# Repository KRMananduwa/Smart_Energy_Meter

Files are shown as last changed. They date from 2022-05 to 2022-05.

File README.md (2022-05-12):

# Smart_Energy_Meter
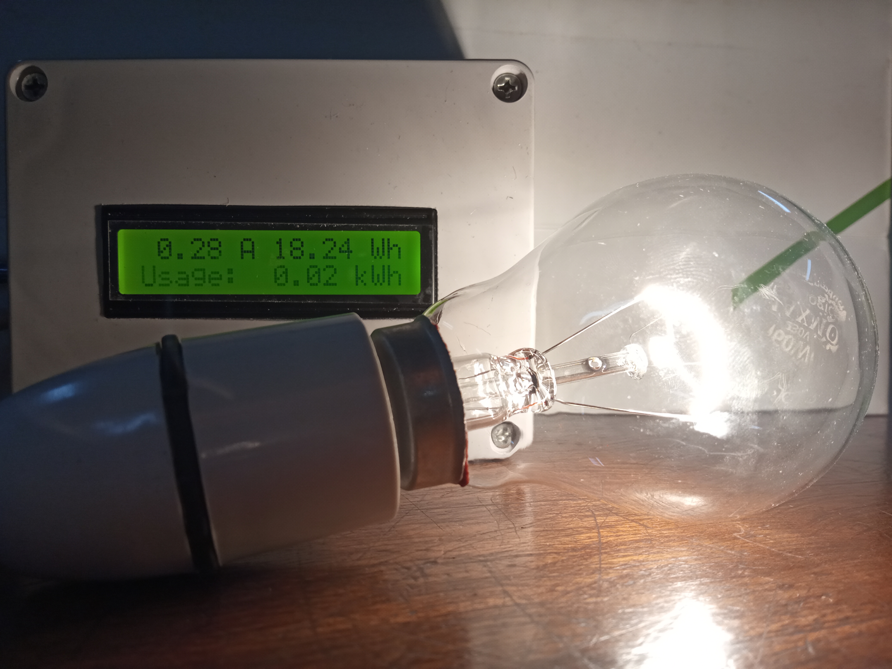
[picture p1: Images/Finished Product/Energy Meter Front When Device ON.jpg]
SmartEnergyMeterImage


A smart energy meter is an electronic device that wirelessly trasnmits information such as consumption of electric energy, voltage levels and current. 
This smart meter can be installed near the meter that supplies power from the mains grid or after the distribution board, indoors or outside the home/office. The speciality of this energy meter can be installed without making any structural changes to your existing electrical supply. The data would be stored in a local database on the computer and can be analysed further.
This project was carried out as a completion of the final year project of the University of Colombo.

https://krmananduwa.github.io/Smart_Energy_Meter/

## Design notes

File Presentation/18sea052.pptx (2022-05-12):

## Smart Energy Meter

Kanishka Rangana (18sea052)

## Abstract

- A smart energy meter is an electronic device that records information such as consumption of electric energy, voltage levels and current.
- This meter is used to know how much energy is consumed.
- The Smart meters communicate the information to the consumer for greater clarity of consumption behavior.

## Overview

- Everyone uses energy but hardly anyone measures it.
- Quantifying is the first step in energy saving.
- Intelligent approach to save energy, cost and selection of equipment.

## Project Aims & Objectives

• Designing compact, rugged and cost-effective smart meter.
• Improving the accuracy of the smart meter.

## Advantages of an Smart Energy Meter

- Determining energy consumption of various equipment
- Determining energy consumption patterns
- Possibility to make informed SMART decisions to reduce energy usage opting for more efficient equipment based on capital cost, ROI.
- Possibility to reduce energy usage by comparing with the initial usage of ones own self
- Possibility to take advantage of off-peak tariff, SMARTLY.

## Methodology

• Material Selection & Cost survey
• Time Planning
• Circuit simulation and prototyping
• Testing & evaluation
• Software and hardware implementation
• Debug errors and moderations
• Designing mechanical parts via CAD/CAM
• Finalizing the instrument and handing over the project

## Fundamentals of Smart Energy Meter

- This project is based on Arduino platform and Arduino-Nano board is the major component of this meter.
- Current is measured through the ACS 712 current sensor.
- ESP8266 Wi-Fi module is used to transmit data which includes energy consumption details, to the attached display via i2c module portraying real-time values.
- Values are forwarded to log the data employing IFTTT platform enabling remote monitoring of data via a web based interface.

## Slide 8

Problems Encountered

- Noise generation
- CT coil has been used successfully to reduce noise and signal was enhanced but when amperage is less than 5A, reading is not very accurate.
- Initially for power supply, laptop USB port was used and it was observed that noise level depends on noise of power supply.
- USB power adapter with minimum noise was used thereafter.
- Problems that could not be overcome
- Transferring data to the web interface from database.

## EXPERIMENTAL RESULTS

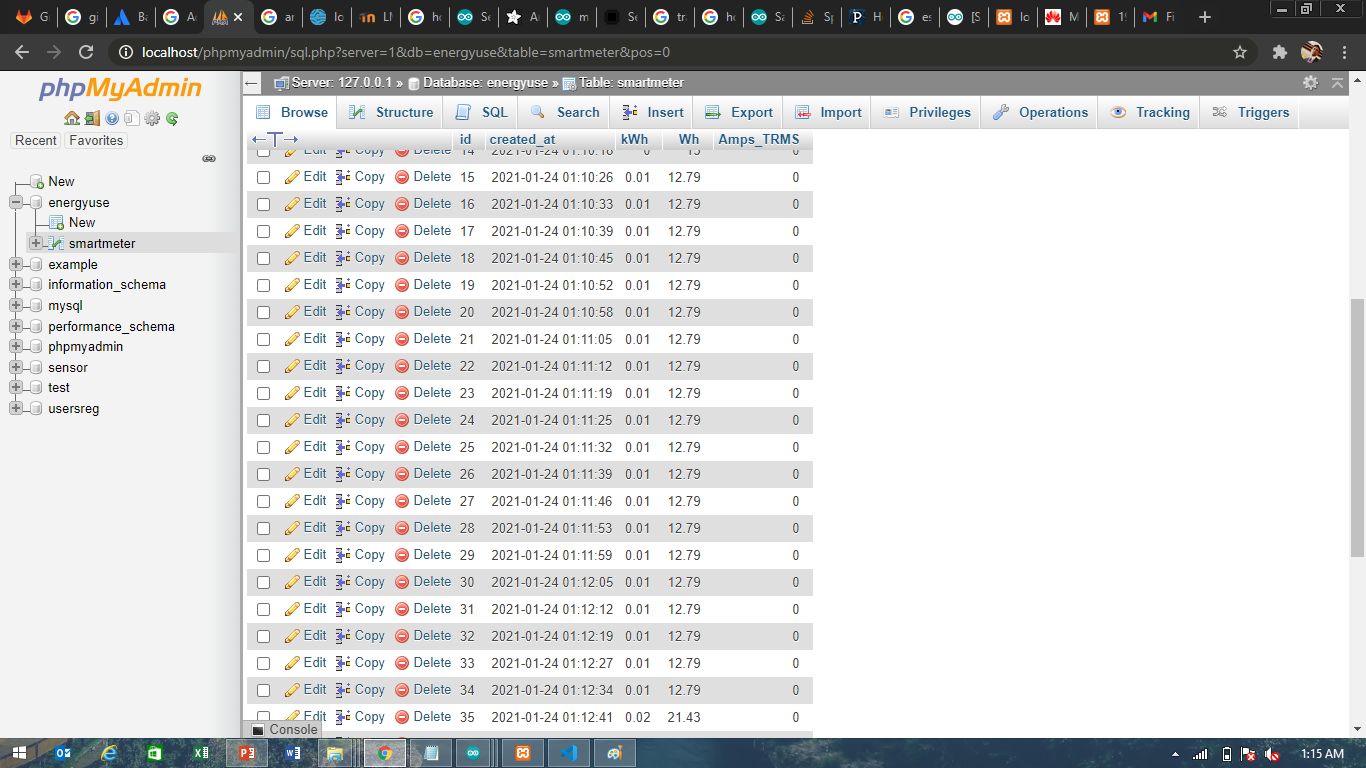
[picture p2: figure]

## Thank You

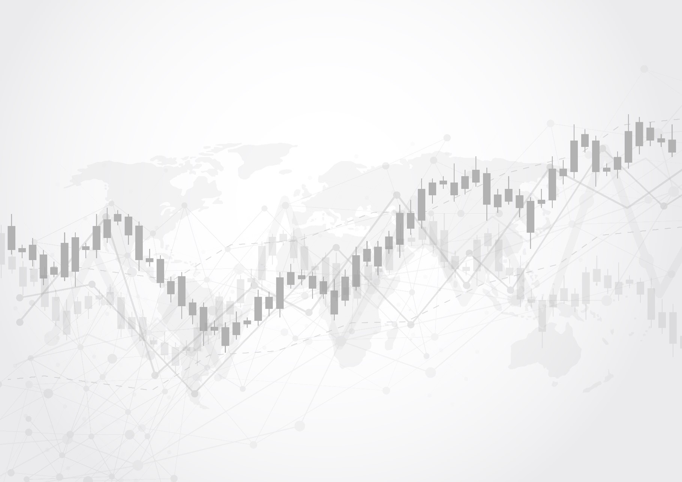
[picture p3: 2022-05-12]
Software/xampp/SmartMeterWeb/images/home.jpg

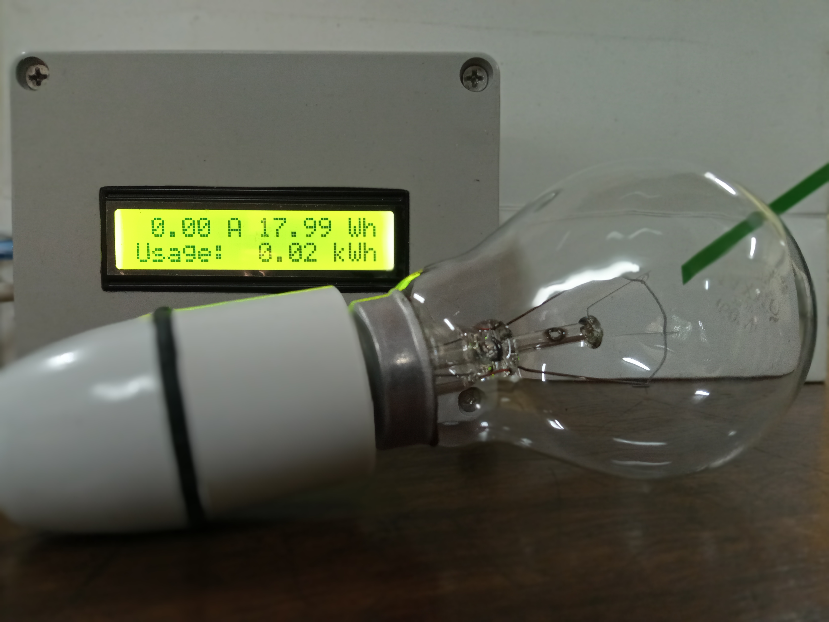
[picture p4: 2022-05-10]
Images/Finished Product/Energy Meter Front When Device OFF 1.jpg

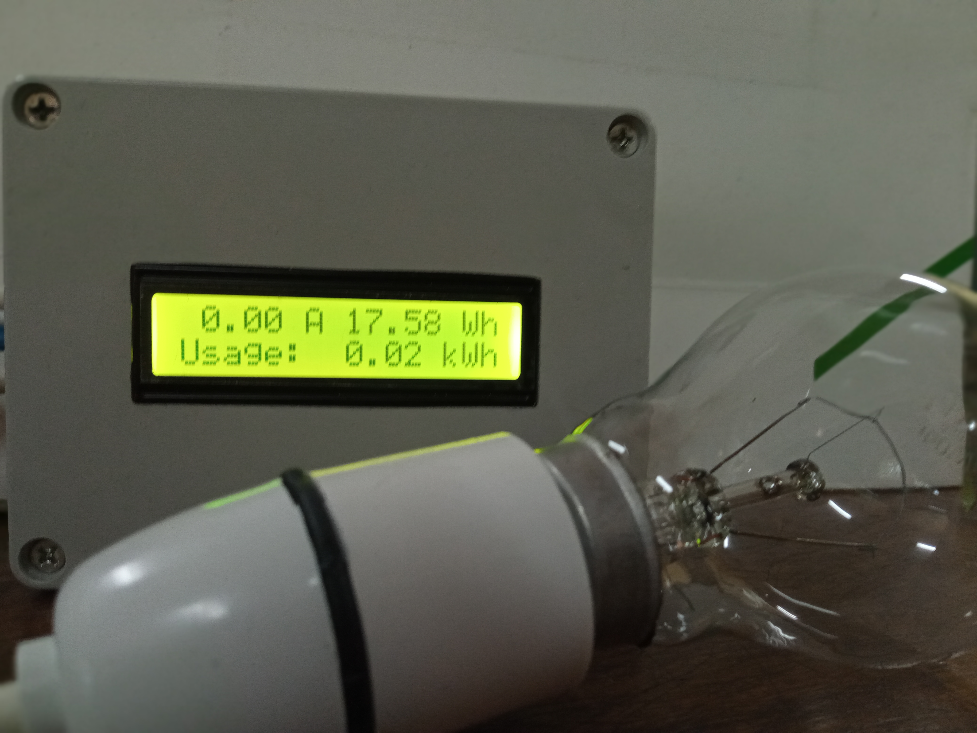
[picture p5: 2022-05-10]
Images/Finished Product/Energy Meter Front When Device OFF.jpg

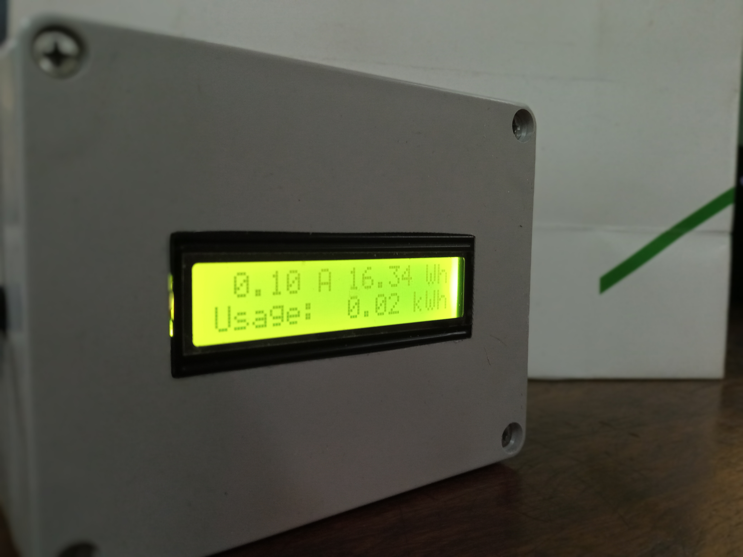
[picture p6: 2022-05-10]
Images/Finished Product/Energy Meter Front.jpg

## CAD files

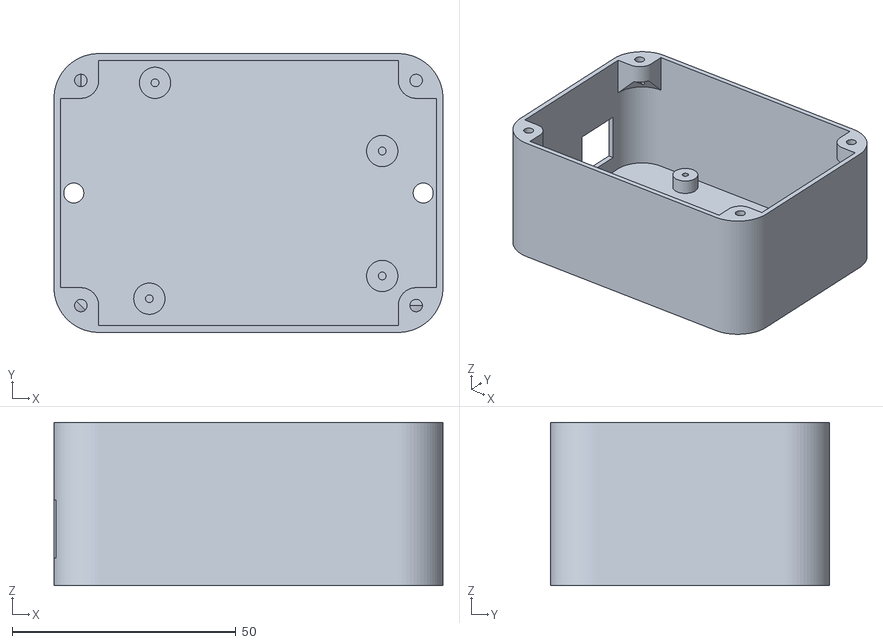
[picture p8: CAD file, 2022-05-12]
CadCamFiles/Enclosure/Bottom.stl
87.0 x 62.3 x 36.5

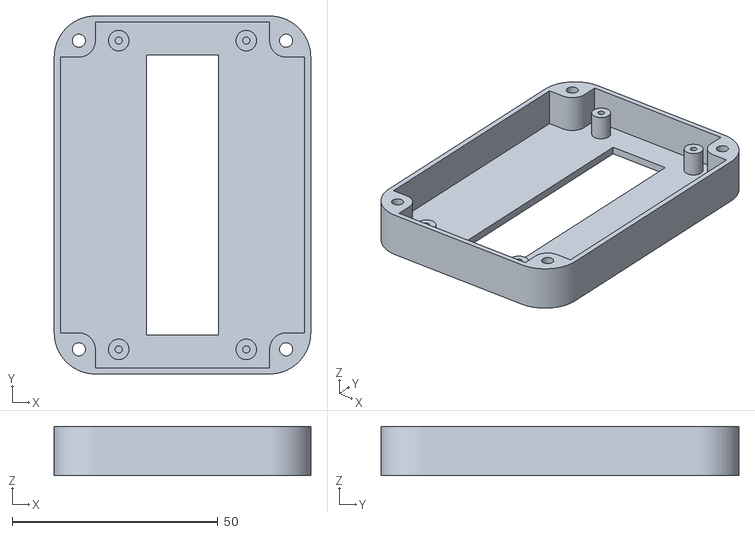
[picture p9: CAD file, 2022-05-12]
CadCamFiles/Enclosure/TopCover.stl
62.3 x 87.0 x 12.0

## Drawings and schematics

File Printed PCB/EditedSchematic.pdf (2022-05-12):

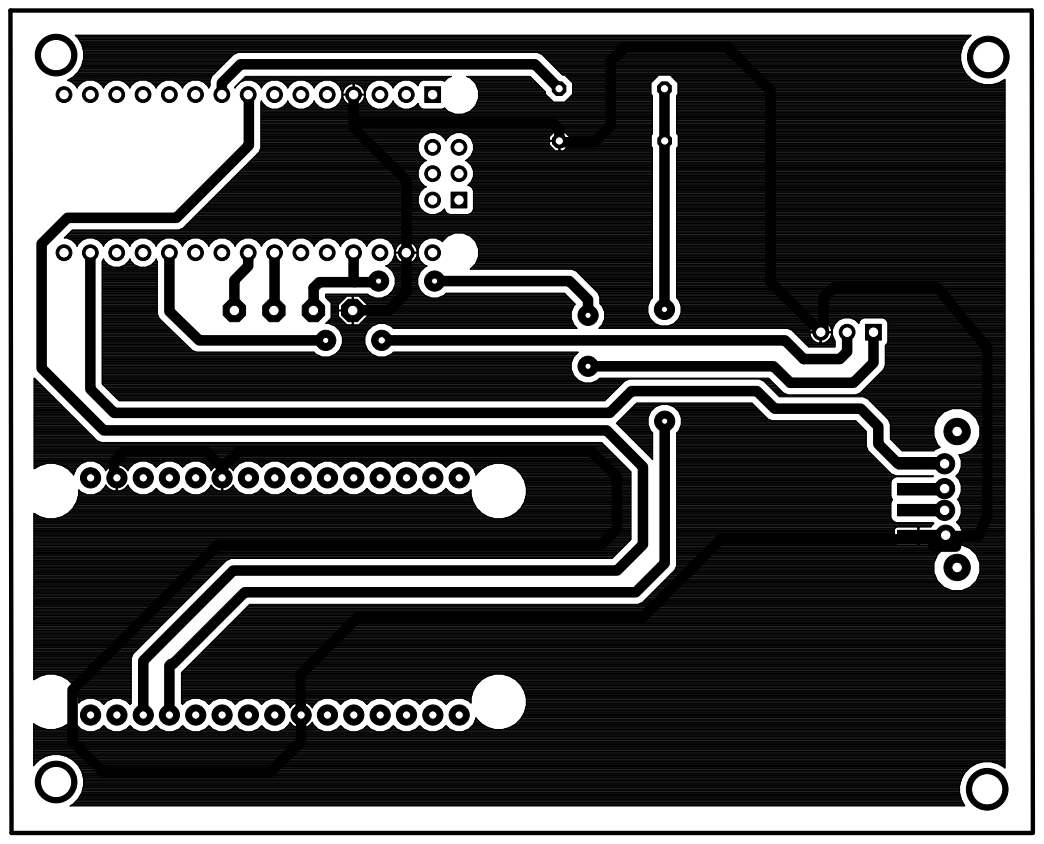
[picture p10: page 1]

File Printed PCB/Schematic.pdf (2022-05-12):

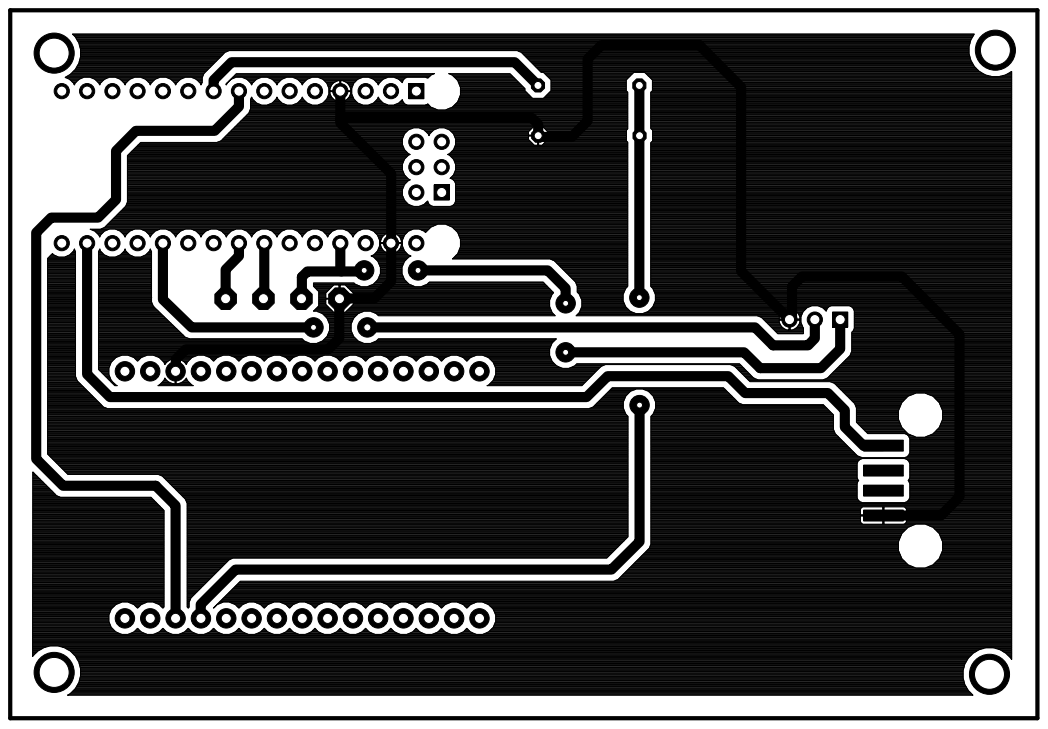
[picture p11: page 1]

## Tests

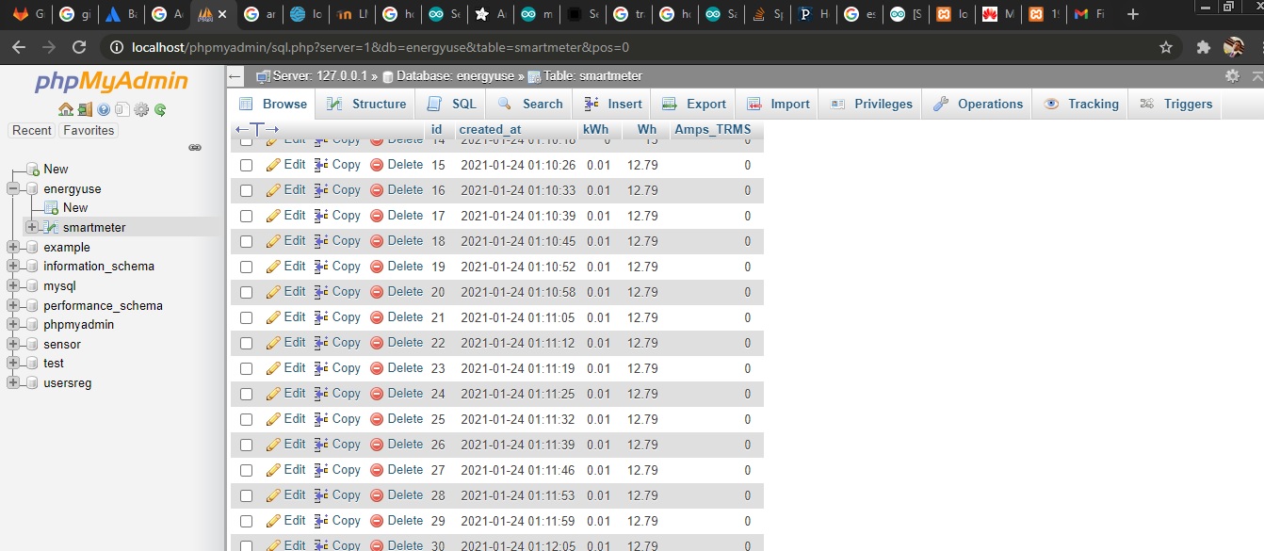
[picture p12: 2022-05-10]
Images/Database/DataBase Results.jpg

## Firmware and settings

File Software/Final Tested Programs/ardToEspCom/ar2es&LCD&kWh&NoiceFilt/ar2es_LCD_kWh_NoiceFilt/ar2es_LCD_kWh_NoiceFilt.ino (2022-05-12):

#include "ACS712.h"
#include <SoftwareSerial.h>
#include <Filters.h>                      //This library can check by it's .cpp file

#include <LiquidCrystal_I2C.h>    //LCD ic library
#define I2C_ADDR 0x27 //I2C adress
#define BACKLIGHT_PIN 3 // Declaring LCD Pins
#define En_pin 2
#define Rw_pin 1
#define Rs_pin 0
#define D4_pin 4
#define D5_pin 5
#define D6_pin 6
#define D7_pin 7

LiquidCrystal_I2C lcd(I2C_ADDR,En_pin,Rw_pin,Rs_pin,D4_pin,D5_pin,D6_pin,D7_pin); //Declaring the lcd

#define ACS_Pin A1                        //Sensor data pin on A1 analog input
ACS712 sensor(ACS712_30A, A1);            // We have 30 amps version sensor connected to A1 pin of arduino
SoftwareSerial espSerial(5, 6);

String str;
unsigned long last_time =0;
unsigned long current_time =0;
float Wh =0 ;
float kWh =0;
char watt[5]; //Make an array to store power

float ACS_Value;                              //Here we keep the raw data valuess
float testFrequency = 50;                    // test signal frequency (Hz)
float windowLength = 40.0/testFrequency;     // how long to average the signal, for statistist

float intercept = 0; // to be adjusted based on calibration testing
float slope = 0.0752; // to be adjusted based on calibration testing

float Amps_TRMS; // estimated actual current in amps
float P; //Power

unsigned long printPeriod = 1000; // in milliseconds
// Track time in milliseconds since last reading 
unsigned long previousMillis = 0;

void setup() {
  Serial.begin( 115200 );    // Start the serial port
  espSerial.begin(115200);
  sensor.calibrate();
  pinMode(ACS_Pin,INPUT);  //Define the pin mode

  digitalWrite(2,HIGH);
  lcd.begin (16,2);
  lcd.setBacklightPin(BACKLIGHT_PIN,POSITIVE);
  lcd.setBacklight(HIGH); //Lighting backlight
  lcd.home ();
}

void loop() {
  RunningStatistics inputStats;                 // create statistics to look at the raw test signal
  inputStats.setWindowSecs( windowLength );     //Set the window length
   
  while( true ) {
  float U = 230;
  float I = sensor.getCurrentAC();
  
  if(I<0.1){
    float P = 0;
  }else{
    float P = U * I;

     //convert power into Wh.
    last_time = current_time;
    current_time = millis();    
    Wh = Wh+  P *(( current_time -last_time) /3600000.0) ;
    kWh = kWh+  ((P *(( current_time -last_time)/1000.0))/3600000.0); 
  }

    
    ACS_Value = analogRead(ACS_Pin);  // read the analog in value:
    inputStats.input(ACS_Value);  // log to Stats function
        
    if((unsigned long)(millis() - previousMillis) >= printPeriod) { //every second we do the calculation
      previousMillis = millis();   // update time
      
      Amps_TRMS = intercept + slope * inputStats.sigma(); //Calibrate the values

      lcd.clear();               //clear the lcd and print in a certain position
      lcd.setCursor(1,0);
      lcd.print(Amps_TRMS);
      lcd.print(" A");

      lcd.setCursor(8,0);
      lcd.print(Wh);
      lcd.print(" Wh");

      lcd.setCursor(0,1);
      lcd.print("Usage:  ");
      lcd.print(kWh);
      lcd.print(" kWh");

      Serial.println(String("P = ") + P + " Watts"+ "\t Amps: "+ Amps_TRMS);
      str =String("coming from arduino: ")+String("Consumption: ")+String(kWh)+String("kWh")+String("\t")+String("P= ")+String(P)+String("\t")+String("Amps= ")+String(Amps_TRMS);
      espSerial.println(str); 
      /*
      Serial.print( "\t Amps: " ); 
      Serial.print( Amps_TRMS );
      */

    }
  }
}

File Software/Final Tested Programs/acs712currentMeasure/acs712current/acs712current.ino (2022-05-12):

//Code 3
/* This code works with ACS712 current sensor, it permits the calculation of the signal TRMS
 * Visit www.surtrtech.com for more details
 */

#include <Filters.h>                      //This library does a massive work check it's .cpp file

#define ACS_Pin A1                        //Sensor data pin on A0 analog input

float ACS_Value;                              //Here we keep the raw data valuess
float testFrequency = 50;                    // test signal frequency (Hz)
float windowLength = 40.0/testFrequency;     // how long to average the signal, for statistist



float intercept = 0; // to be adjusted based on calibration testing
float slope = 0.0752; // to be adjusted based on calibration testing
                      //Please check the ACS712 Tutorial video by SurtrTech to see how to get them because it depends on your sensor, or look below


float Amps_TRMS; // estimated actual current in amps

unsigned long printPeriod = 1000; // in milliseconds
// Track time in milliseconds since last reading 
unsigned long previousMillis = 0;

void setup() {
  Serial.begin( 9600 );    // Start the serial port
  pinMode(ACS_Pin,INPUT);  //Define the pin mode
}

void loop() {
  RunningStatistics inputStats;                 // create statistics to look at the raw test signal
  inputStats.setWindowSecs( windowLength );     //Set the window length
   
  while( true ) {   
    ACS_Value = analogRead(ACS_Pin);  // read the analog in value:
    inputStats.input(ACS_Value);  // log to Stats function
        
    if((unsigned long)(millis() - previousMillis) >= printPeriod) { //every second we do the calculation
      previousMillis = millis();   // update time
      
      Amps_TRMS = intercept + slope * inputStats.sigma();

      Serial.print( "\t Amps: " ); 
      Serial.print( Amps_TRMS );

    }
  }
}

/* About the slope and intercept
 * First you need to know that all the TRMS calucations are done by functions from the library, it's the "inputStats.sigma()" value
 * At first you can display that "inputStats.sigma()" as your TRMS value, then try to measure using it when the input is 0.00A
 * If the measured value is 0 like I got you can keep the intercept as 0, otherwise you'll need to add or substract to make that value equal to 0
 * In other words " remove the offset"
 * Then turn on the power to a known value, for example use a bulb or a led that ou know its power and you already know your voltage, so a little math you'll get the theoritical amps
 * you divide that theory value by the measured value and here you got the slope, now place them or modify them
 */

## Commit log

2022-05-12 Add files via upload
    This folder includes the simulation file of the circuit.
2022-05-12 Add files via upload
    Enclosure cad cam file.
    [Bottom.stl, TopCover.stl]
2022-05-12 Add files via upload
    PCB design file for mounting the modules.
    [SmartMeter.sch]
2022-05-12 Add files via upload
    PCB design for print.
